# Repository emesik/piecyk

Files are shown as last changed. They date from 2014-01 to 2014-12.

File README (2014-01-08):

This is my first project based on AVR microcontroller (and any MCU in general).
It is used to keep track of temperature and control the heating system at home.

General principles:
 * piecyk measures temperature using LM35 analog sensor,
 * it has MIN and MAX temperature defined,
 * whenever current temperature drops to MIN or below, the heating is turned on,
 * whenever current temperature rises to MAX or over, the heating is turned off,
 * such a switch is being done using a NPN transistor to enable +12V DC circuit,
 * same circuit is used to power the controller itself, stepped down to +5V DC,
 * both MIN and MAX temperatures are programmable by MODE, UP and DOWN buttons,
 * a 2x16 LCD displays all these three values,
 * a LED turns on together with the heating.

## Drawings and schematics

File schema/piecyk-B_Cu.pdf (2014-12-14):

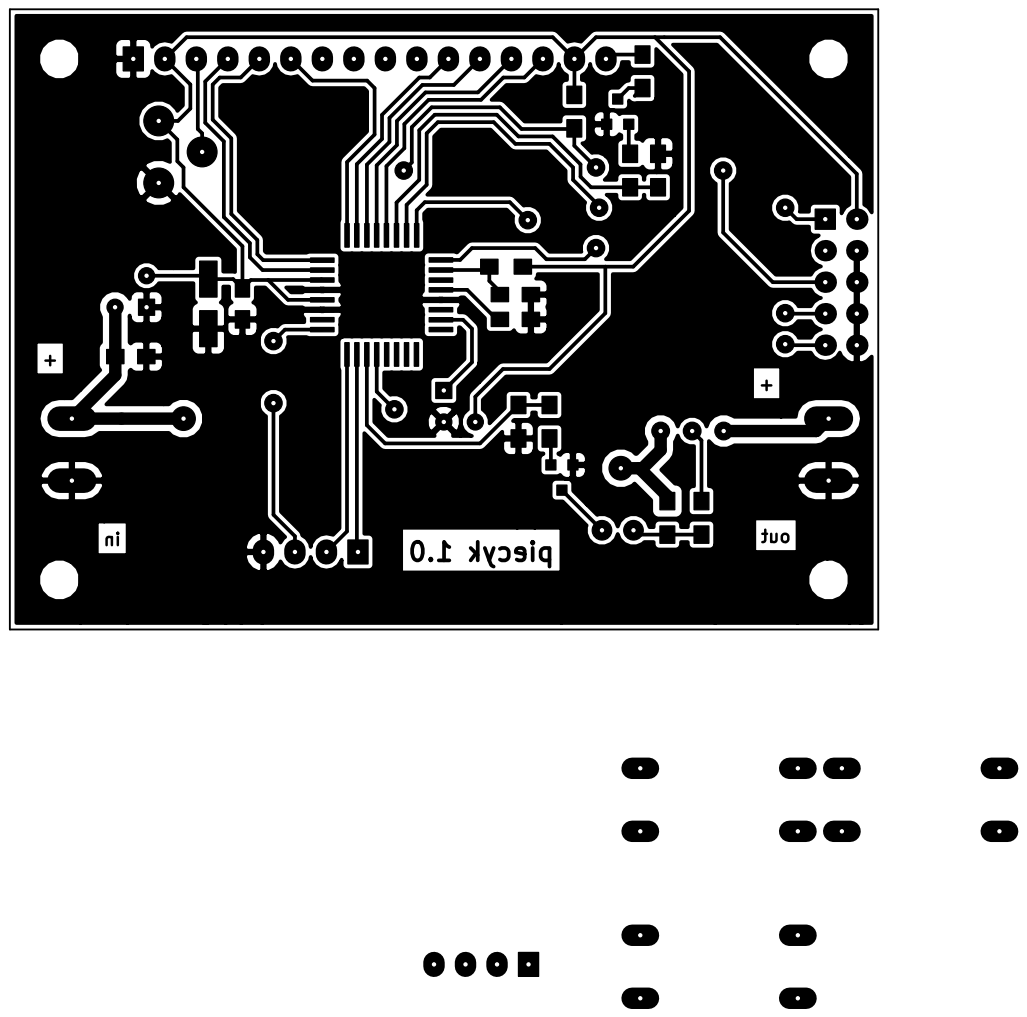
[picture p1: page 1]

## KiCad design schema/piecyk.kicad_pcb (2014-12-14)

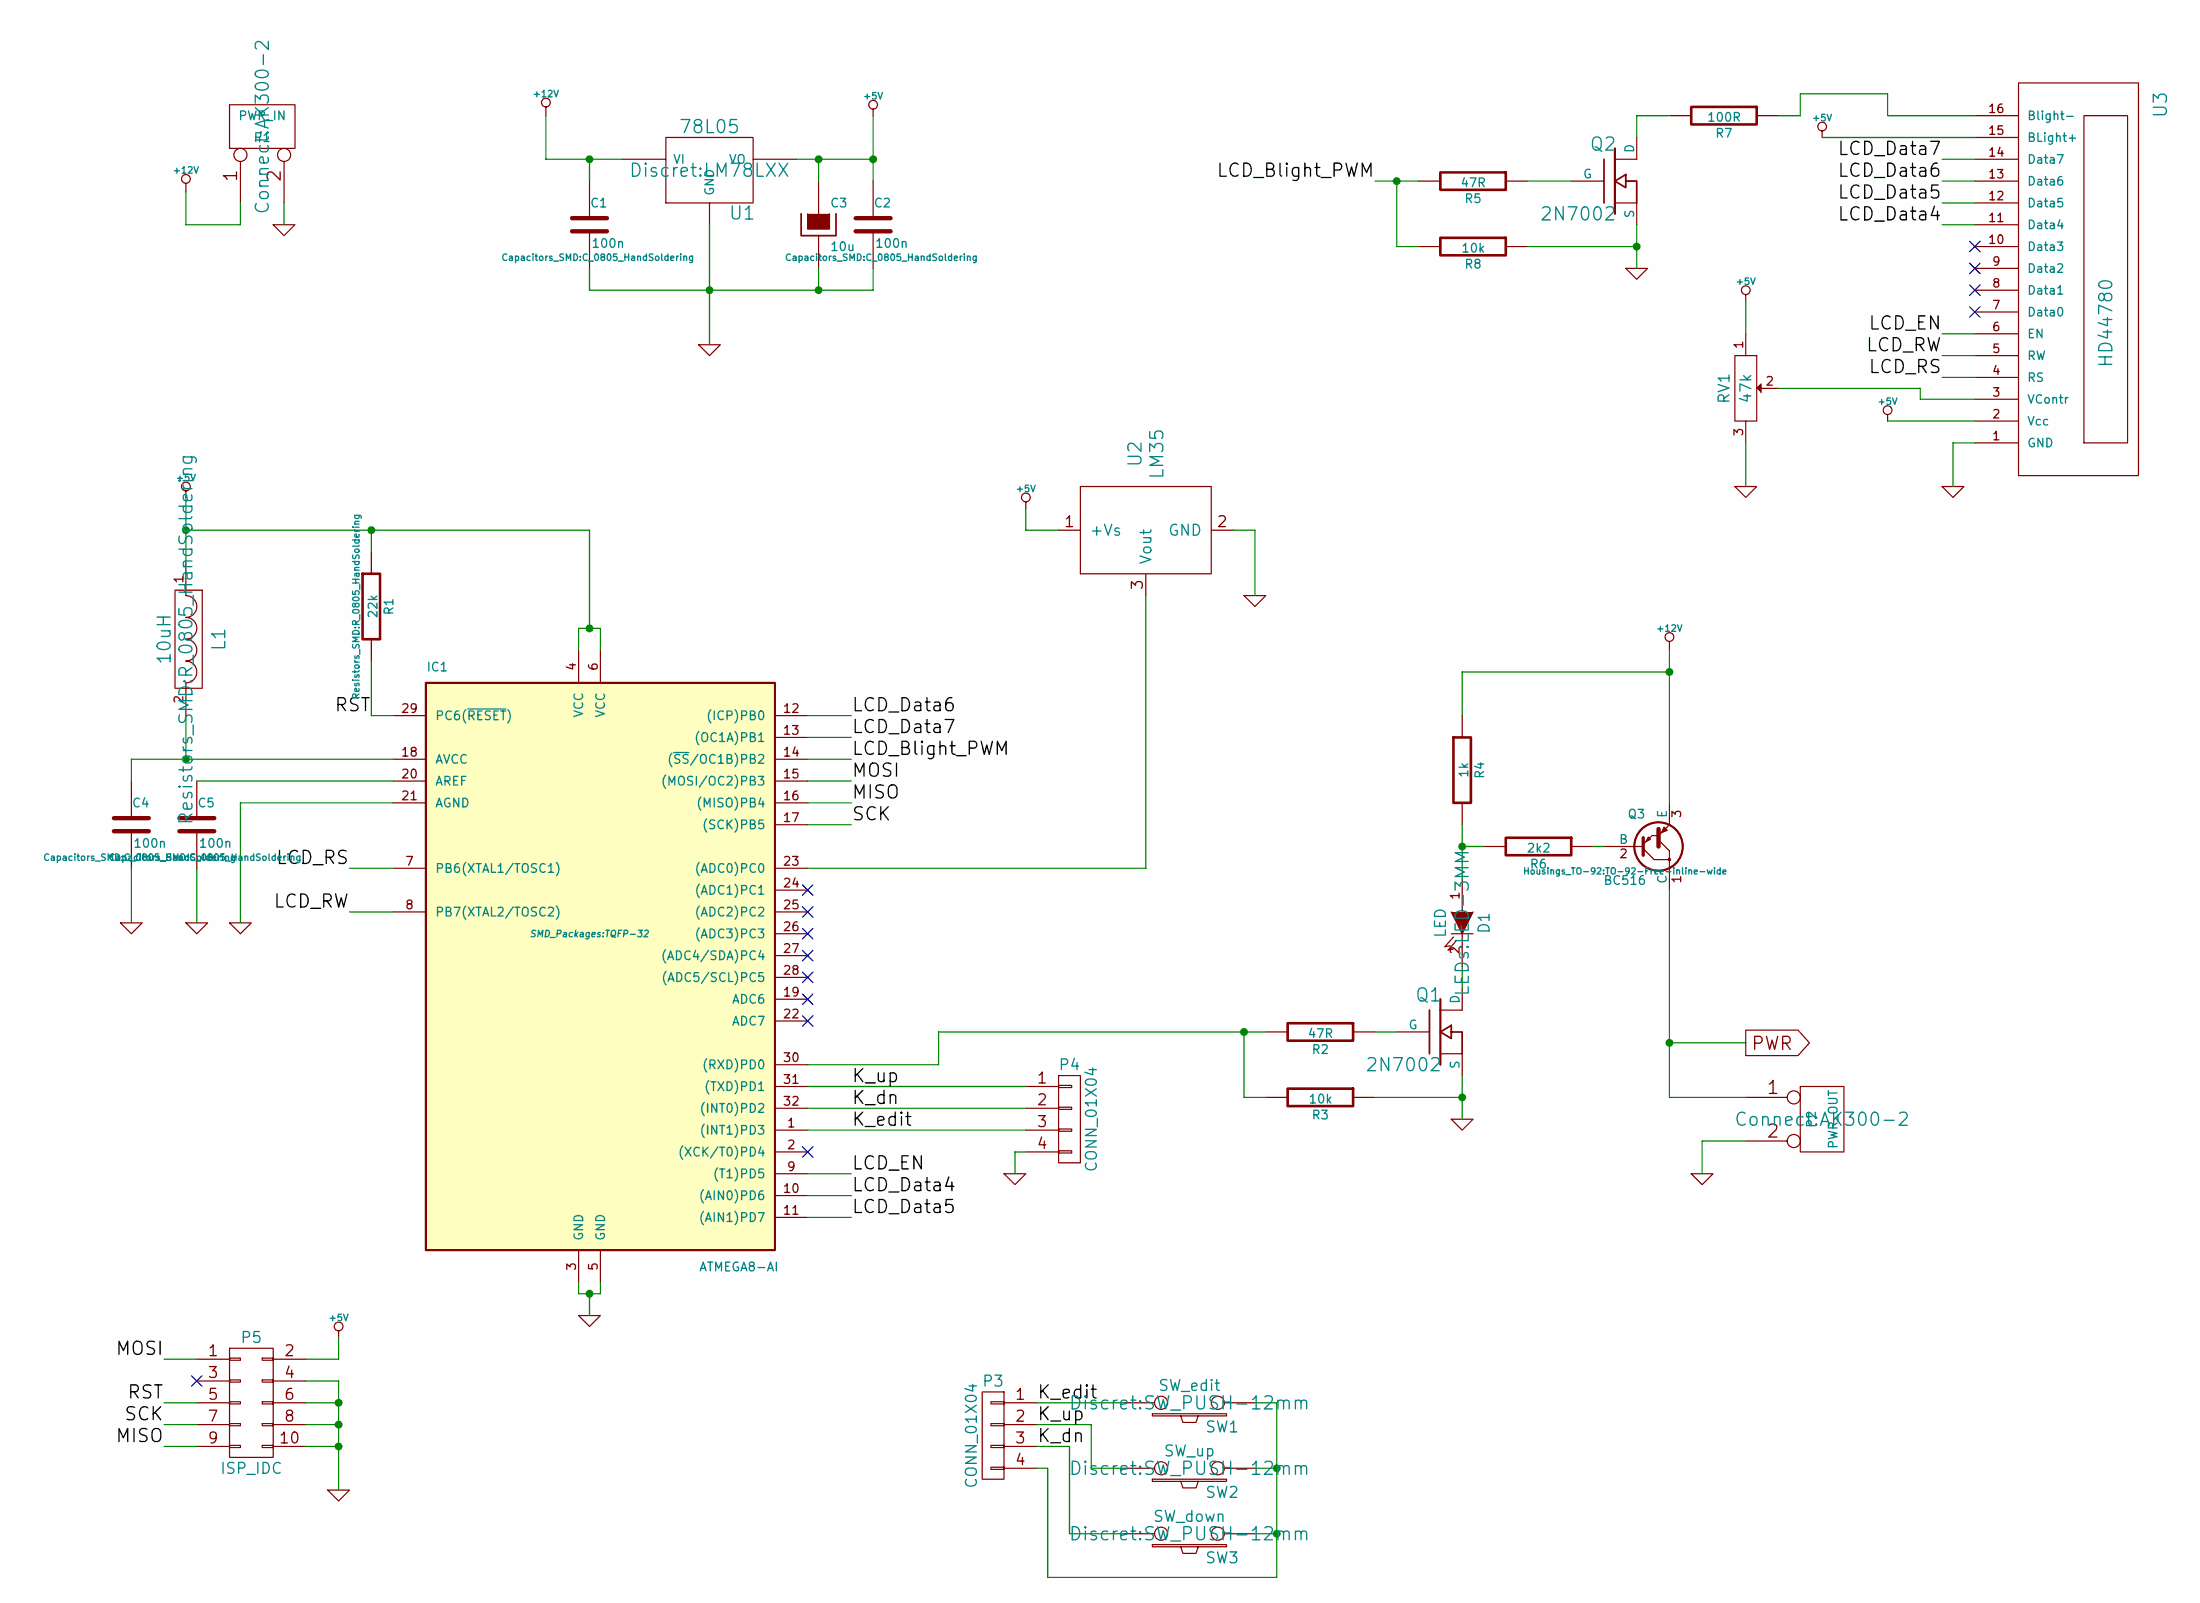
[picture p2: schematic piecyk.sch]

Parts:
C1, C2, C4, C5: 100n; C_0805_HandSoldering
C3: 10u; TantalC_SizeA_EIA-3216_HandSoldering
D1: LED; LED-3MM
IC1: ATMEGA8-AI; TQFP-32
L1: 10uH; R_0805_HandSoldering
P1: PWR_IN; AK300-2
P2: PWR_OUT; AK300-2
P3, P4: CONN_01X04; Pin_Header_Angled_1x04
P5: ISP_IDC; Pin_Header_Straight_2x05
Q1, Q2: 2N7002; SOT-23-GDS
Q3: BC516; TO-92-Free-inline-wide
R1: 22k; R_0805_HandSoldering
R2, R5: 47R; R_0805_HandSoldering
R3, R8: 10k; R_0805_HandSoldering
R4: 1k; R_0805_HandSoldering
R6: 2k2; R_0805_HandSoldering
R7: 100R; R_0805_HandSoldering
RV1: 47k; Potentiometer_VishaySpectrol-Econtrim-Type36P
SW1: SW_edit; SW_PUSH-12mm
SW2: SW_up; SW_PUSH-12mm
SW3: SW_down; SW_PUSH-12mm
U1: 78L05; LM78LXX
U2: LM35
U3: HD44780; Pin_Header_Straight_1x16

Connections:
+5V: C2.1, C3.1, IC1.4 (VCC), IC1.6 (VCC), L1.1, P5.2, R1.1, RV1.1, U1.VO, U2.1 (+Vs), U3.2 (Vcc), U3.15 (BLight+)
+12V: C1.1, P1.1, Q3.3 (E), R4.1, U1.VI
/K_dn: IC1.32 ((INT0)PD2), P3.3, P4.2, SW3.1
/K_edit: IC1.1 ((INT1)PD3), P3.1, P4.3, SW1.1
/K_up: IC1.31 ((TXD)PD1), P3.2, P4.1, SW2.1
/LCD_Blight_PWM: IC1.14 ((~SS~/OC1B)PB2), R5.2, R8.2
/LCD_Data4: IC1.10 ((AIN0)PD6), U3.11 (Data4)
/LCD_Data5: IC1.11 ((AIN1)PD7), U3.12 (Data5)
/LCD_Data6: IC1.12 ((ICP)PB0), U3.13 (Data6)
/LCD_Data7: IC1.13 ((OC1A)PB1), U3.14 (Data7)
/LCD_EN: IC1.9 ((T1)PD5), U3.6 (EN)
/LCD_RS: IC1.7 (PB6(XTAL1/TOSC1)), U3.4 (RS)
/LCD_RW: IC1.8 (PB7(XTAL2/TOSC2)), U3.5 (RW)
/MISO: IC1.16 ((MISO)PB4), P5.9
/MOSI: IC1.15 ((MOSI/OC2)PB3), P5.1
/RST: IC1.29 (PC6(~RESET~)), P5.5, R1.2
/SCK: IC1.17 ((SCK)PB5), P5.7
GND: C1.2, C2.2, C3.2, C4.2, C5.2, IC1.3 (GND), IC1.5 (GND), IC1.21 (AGND), P1.2 (PM), P2.2 (PM), P4.4, P5.4, P5.6, P5.8, P5.10, Q1.S, Q2.S, R3.1, R8.1, RV1.3, U1.GND, U2.2 (GND), U3.1 (GND)
unnamed: C4.1, IC1.18 (AVCC), L1.2
unnamed: C5.1, IC1.20 (AREF)
unnamed: D1.1 (A), R4.2, R6.2
unnamed: D1.2 (K), Q1.D
unnamed: IC1.23 ((ADC0)PC0), U2.3 (Vout)
unnamed: IC1.30 ((RXD)PD0), R2.2, R3.2
unnamed: P3.4, SW1.2, SW2.2, SW3.2
unnamed: Q1.G, R2.1
unnamed: Q2.D, R7.2
unnamed: Q2.G, R5.1
unnamed: Q3.2 (B), R6.1
unnamed: R7.1, U3.16 (Blight-)
unnamed: RV1.2, U3.3 (VContr)
PWR: P2.1, Q3.1 (C)

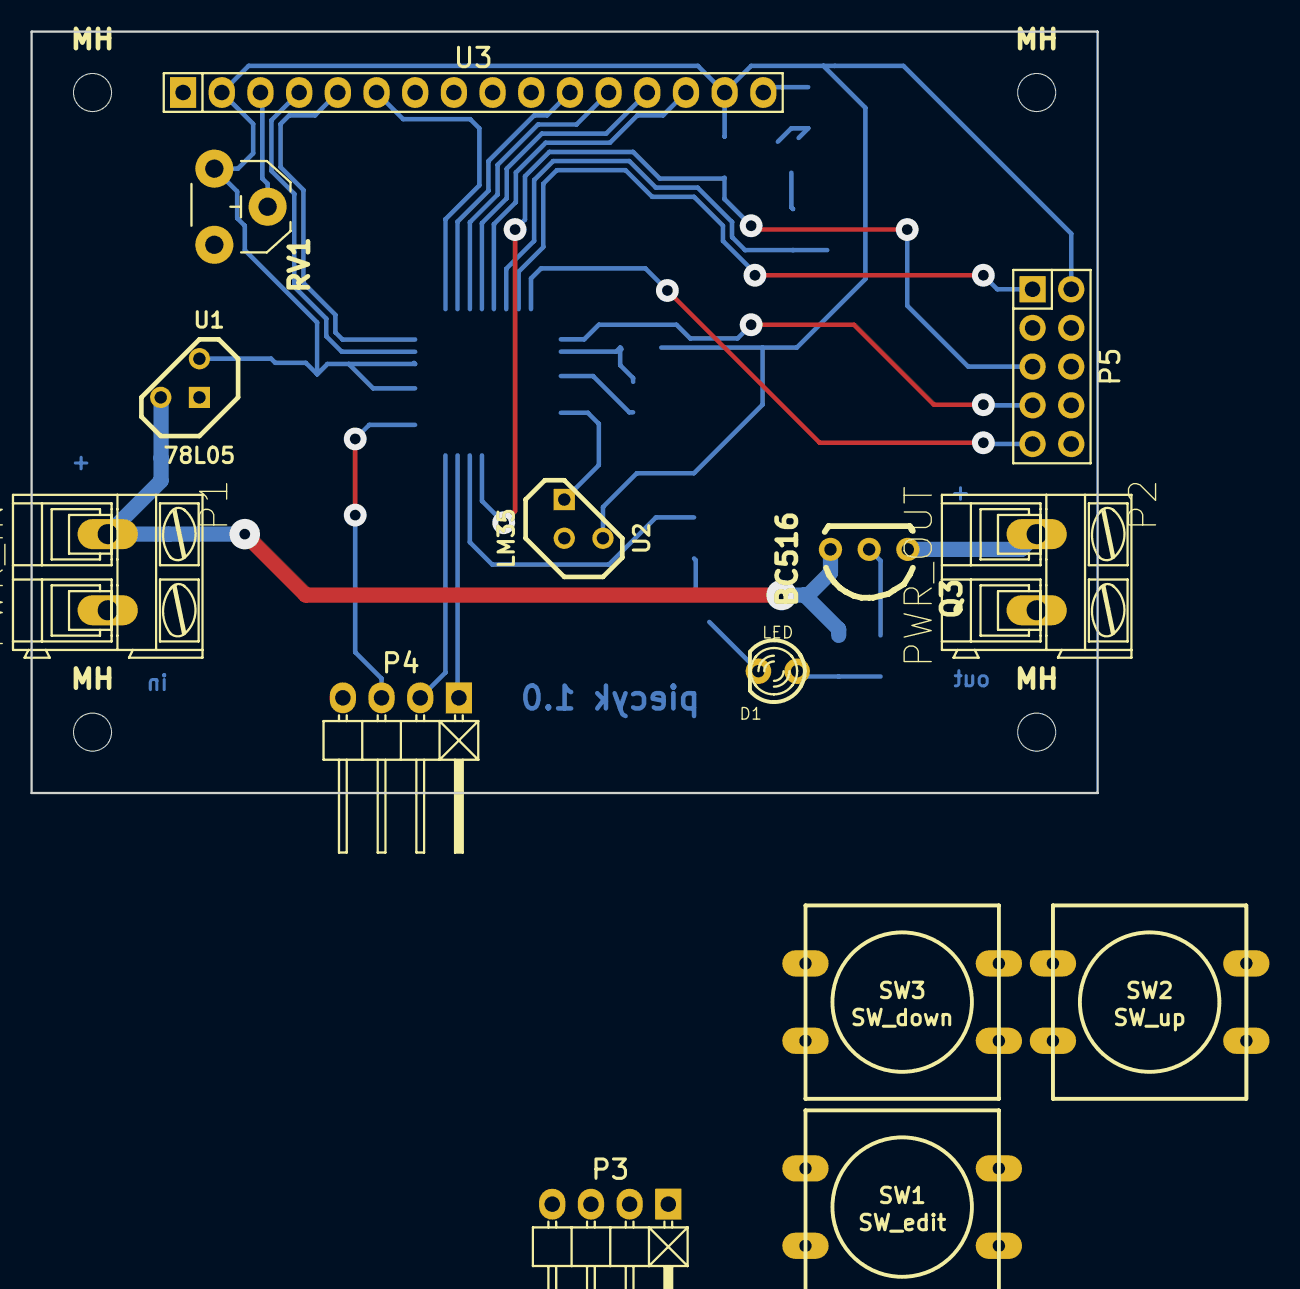
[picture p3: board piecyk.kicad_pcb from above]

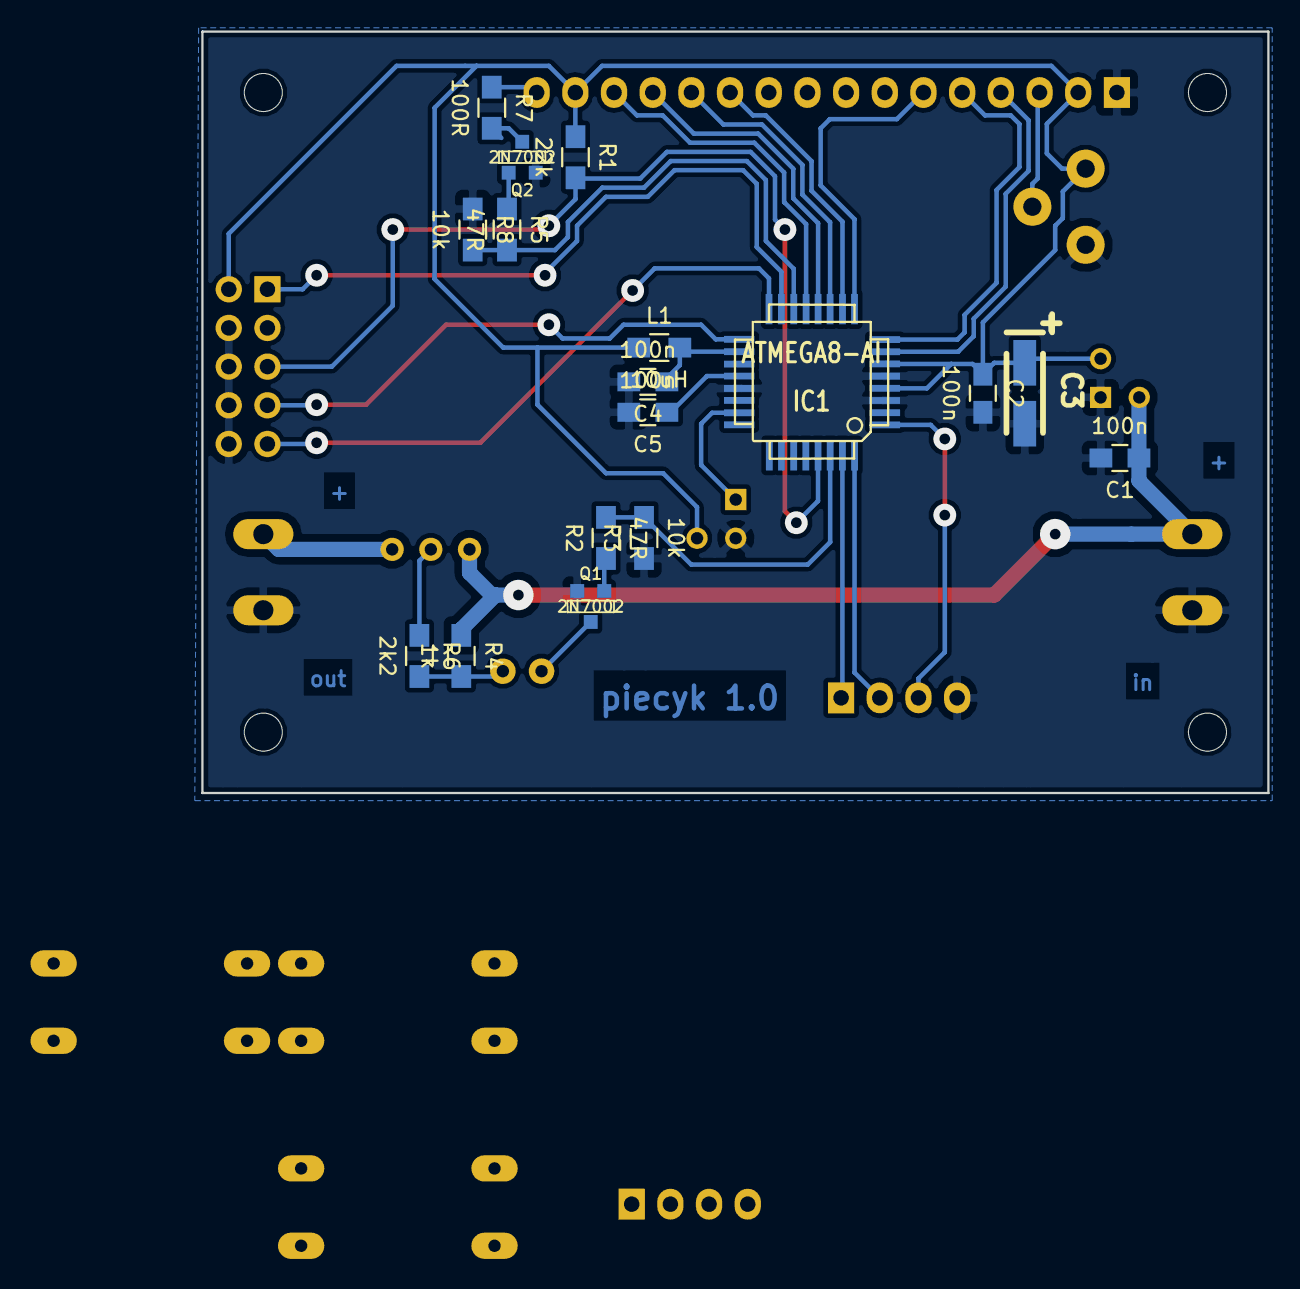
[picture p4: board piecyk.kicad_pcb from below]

Board: 2 copper layers, 70.0 x 50.0 mm, 35 parts (17 on the bottom side), 32 nets.

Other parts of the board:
MH: MountingHole_2-5mm_RevA_Date21Jun2010; MountingHole_2-5mm
MH#2, MH#3, MH#4: MountingHole_2-5mm_RevA_Date21Jun2010; MountingHole_2-5mm

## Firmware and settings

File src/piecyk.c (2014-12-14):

#include <stdlib.h>
#include <string.h>
#include <avr/interrupt.h>
#include <avr/io.h>
#include <avr/eeprom.h>
#include <avr/pgmspace.h>
#include <util/delay.h>

#include <hd44780_low.h>
#include <hd44780fw.h>

FUSES =
{
	.low = LFUSE_DEFAULT & FUSE_BODLEVEL & FUSE_BODEN,
	.high = HFUSE_DEFAULT & FUSE_EESAVE,
	/* WARNING: These settings cannot be written from a .hex file without external tools.
	 * Fusebits are redefined in Makefile and that setting is the working one.
	 */
};

/* The sensor shows some kind of variation, jumping even a full centigrade every
 * few seconds. For the heating we need very slow responsiveness, so the samples
 * will be gathered in a table and averaged.
 */
#ifdef DEBUG
#define		SAMPLE_BUFFER_SIZE	10
#else
#define		SAMPLE_BUFFER_SIZE	100		// remember this chip has 1K only
#endif
#define		INVALID_TEMP		-(300 << 2)	// mordor
int16_t *samples;		// keep full 10-bit sample
unsigned int samples_idx = 0;
uint8_t buffer_filled = 0;

/* WARNING: all temperatures are measured in 0,25C units, 10 bit */
#define		MIN_VALID_TEMP	0
#define		MAX_VALID_TEMP	(50 << 2)
#define		DEFAULT_MIN		(22 << 2)		// 22,00
#define		DEFAULT_MAX		(22 << 2) + 2	// 22,50
uint16_t volatile temp_min = DEFAULT_MIN, temp_max = DEFAULT_MAX;
uint8_t heating_state = 0;

// the permanent storage of programmed temps and last state
uint16_t EEMEM perm_temp_min = DEFAULT_MIN;
uint16_t EEMEM perm_temp_max = DEFAULT_MAX;
uint8_t EEMEM perm_heating_state = 1;
uint8_t need_store = 0;

inline void restore_parameters()
{
	cli();
	eeprom_busy_wait();
	temp_min = eeprom_read_word(&perm_temp_min);
	temp_max = eeprom_read_word(&perm_temp_max);
	heating_state = eeprom_read_byte(&perm_heating_state);
	sei();
}

void save_parameters()
{
	cli();
	eeprom_busy_wait();
	eeprom_write_word(&perm_temp_min, temp_min);
	eeprom_write_word(&perm_temp_max, temp_max);
	eeprom_write_byte(&perm_heating_state, heating_state);
	sei();
}

// The LCD configs
struct hd44780fw_conf lcd_conf;
struct hd44780_l_conf lcd_low_conf;
volatile uint8_t display_need_refresh = 0;

/*
 *	The LCD desired structure during normal operation
 *	   0123456789abcdef
 *
 *	0  Temp= *Max 21,0C
 *	1  20,5C *Min 20,0C
 *
 *	         ^-------- indicates the value is being edited
 *
 */
#define		DISPLAY_SIZE	0x20
#define		GATHER_IDX		0x04
#define		CUR_VAL_IDX		0x10
#define		MIN_EDIT_IDX	0x16
#define		MIN_VAL_IDX		0x1b
#define		MAX_EDIT_IDX	0x06
#define		MAX_VAL_IDX		0x0b

const char template[DISPLAY_SIZE] PROGMEM	= "Temp   Max     C    C  Min     C";
const char intro[DISPLAY_SIZE] PROGMEM		= "piecyk v1.0     zaraz grzejemy! ";
const char fractions[4] PROGMEM = "0358";

#define		MIN_BRIGHTNESS	0x0060
#define		MAX_BRIGHTNESS	0x0300
#define		DIM_STEP_UP		16
#define		DIM_STEP_DN		3
uint16_t	brightness = MIN_BRIGHTNESS;
#define		IDLE_TOP		0x60
uint16_t	idle = IDLE_TOP;

inline void init_display()
{
	char *display_buf = malloc(DISPLAY_SIZE + 1);

	// init backlight PWM
	DDRB |= (1 << PB2);
	// phase-correct 10bit PWM, OC1B output
	TCCR1A = (1 << COM1B1) | (1 << WGM10) | (1 << WGM11);
	// /8 prescaler
	TCCR1B = (1 << CS11);
	// enable overflow interrupt
	TIMSK = (1 << TOIE1);
	OCR1BH = (uint8_t)(brightness >> 8);
	OCR1BL = (uint8_t)(brightness & 0xff);

	// pins connected to PORTB
	DDRB |= (1 << PB7) | (1 << PB6) | (1 << PB1) | (1 << PB0);
	lcd_low_conf.rs_i = 6;
	lcd_low_conf.rw_i = 7;
	lcd_low_conf.db6_i = 0;
	lcd_low_conf.db7_i = 1;

	lcd_low_conf.rs_port =
	lcd_low_conf.rw_port =
	lcd_low_conf.db6_port =
	lcd_low_conf.db7_port =
	&PORTB;

	// pins connected to PORTD
	DDRD |= (1 << PD5) | (1 << PD6) | (1 << PD7);
	lcd_low_conf.en_i = 5;
	lcd_low_conf.db4_i = 6;
	lcd_low_conf.db5_i = 7;

	lcd_low_conf.en_port =
	lcd_low_conf.db4_port =
	lcd_low_conf.db5_port =
	&PORTD;

	lcd_low_conf.line1_base_addr = 0x00;
	lcd_low_conf.line2_base_addr = 0x40;
	lcd_low_conf.dl = HD44780_L_FS_DL_4BIT;
	lcd_conf.low_conf = &lcd_low_conf;
	lcd_conf.total_chars = 32;
	lcd_conf.font = HD44780_L_FS_F_58;
	lcd_conf.lines = HD44780_L_FS_N_DUAL;

	hd44780fw_init(&lcd_conf);
	hd44780_l_disp(&lcd_low_conf, HD44780_L_DISP_D_ON, HD44780_L_DISP_C_OFF, HD44780_L_DISP_B_OFF);

	memcpy_P(display_buf, &intro, DISPLAY_SIZE);
	*(display_buf + DISPLAY_SIZE) = '\0';
	hd44780fw_write(&lcd_conf, display_buf, 0, HD44780FW_WR_CLEAR_BEFORE);

	display_need_refresh = 1;
	free(display_buf);
}

inline void init_analog_temp()
{
	/*
	 * Based on https://sites.google.com/site/qeewiki/books/avr-guide/analog-input
	 *
	 * Initialize ADMUX register with new value
	 * REFS0 = 1, REFS1 = 1:	use Aref
	 * ADLAR = 0:				10-bit resolution
	 * MUX = 0:					ADC0 (PC0) is the input
	 */
	ADMUX = (1 << REFS0) | (1 << REFS1);
	// enable ADC, set 128 prescaler
	ADCSRA |= (1 << ADEN) | (1 << ADPS2) | (1 << ADPS1) | (1 << ADPS0);
	// set other pins as output and set high state
	DDRC = ~(1 << PC0);
	PORTC |= ~(1 << PC0);
	// create buffer for samples and empty it
	samples = malloc(SAMPLE_BUFFER_SIZE * sizeof(int16_t));
	for (unsigned int i = 0; i < SAMPLE_BUFFER_SIZE; i++) *(samples + i) = INVALID_TEMP;
}

inline void read_temp()
{
	int adcval;
	// start conversion
	ADCSRA |= (1 << ADSC);
	// spinlock until finished
	while (ADCSRA & (1 << ADSC));

	/*
	 * The docs say reading the higher byte causes update. This should not be the case in
	 * per-request conversion, but we keep the convention of reading lower byte first.
	 *
	 */
	adcval = ADCL;
	adcval = (ADCH << 8) + adcval;

	/*
	 * LM35 returns linear function of temperature in Celsius:
	 * Vout = 0V + (t * 0.01V)
	 * As we have 2.56V as Aref and 1024 values of 10-bit resolution,
	 * the maximum resolution is 0,25C.
	 *
	 * We keep full sample.
	 *
	 */
	*(samples + samples_idx++) = adcval;
	// cycle buffer
	if (samples_idx >= SAMPLE_BUFFER_SIZE) samples_idx = 0;
}

uint16_t get_avg_temp()
{
	unsigned int counted = SAMPLE_BUFFER_SIZE;
	uint32_t sum = 0;

	buffer_filled = 1;
	for (unsigned int i = 0; i < SAMPLE_BUFFER_SIZE; i++) {
		if (*(samples + i) == INVALID_TEMP) {
			counted--;
			buffer_filled = 0;
			continue;
		}
		sum += *(samples + i);
	}
	return sum / counted;
}

#define		KEY_DOWN	(1 << PD2)
#define		KEY_UP		(1 << PD1)
#define		KEY_EDIT	(1 << PD3)
#define		KEYS_ALL	(KEY_EDIT | KEY_DOWN | KEY_UP)

#define		EDIT_NONE		0
#define		EDIT_MAX		1
#define		EDIT_MIN		2
#define		EDIT_INVALID	3
volatile uint8_t edit_mode = EDIT_NONE;

ISR(TIMER0_OVF_vect)
{
	static uint8_t kbd_state, kbd_state_old = 0;
	static uint8_t need_reaction = 0, reacted_state = 0;

	// Switches lower the pin state, so we use negative value
	kbd_state = ~PIND & KEYS_ALL;

	/*
	 * Debouncing, as in:
	 * http://mikrokontrolery.blogspot.com/2011/03/epp-eliminacja-drgan-stykow-omicronns.html
	 *
	 */
	if ((kbd_state == kbd_state_old) && (kbd_state != reacted_state)) {
		need_reaction = 1;
		reacted_state = kbd_state;
	}

	kbd_state_old = kbd_state;

	// React to the keypad state
	if (!need_reaction) return;
	if (kbd_state & KEY_EDIT) {
		// this is not atomic, so we use a temporary var
		uint8_t _edit_mode = edit_mode;
		_edit_mode++;
		if (_edit_mode == EDIT_INVALID) _edit_mode = EDIT_NONE;
		edit_mode = _edit_mode;
	} else if (kbd_state & KEY_DOWN) {
		if ((edit_mode == EDIT_MIN) && (temp_min > MIN_VALID_TEMP)) temp_min--;
		if ((edit_mode == EDIT_MAX) && (temp_max > MIN_VALID_TEMP) &&
				(temp_max > temp_min)) temp_max--;
	} else if (kbd_state & KEY_UP) {
		if ((edit_mode == EDIT_MIN) && (temp_min < MAX_VALID_TEMP) &&
				(temp_min < temp_max)) temp_min++;
		if ((edit_mode == EDIT_MAX) && (temp_max < MAX_VALID_TEMP)) temp_max++;
	}

	need_store = 1;
	need_reaction = 0;
	display_need_refresh = 1;

	idle = IDLE_TOP;
	brightness = MAX_BRIGHTNESS;
}

ISR(TIMER1_OVF_vect) {
	uint16_t cur_bright;

	// increase/decrease duty cycle to target level
	cur_bright = OCR1BL;
	cur_bright |= (OCR1BH << 8);
	if (cur_bright < brightness - DIM_STEP_UP) cur_bright += DIM_STEP_UP;
	if (cur_bright > brightness + DIM_STEP_DN) cur_bright -= DIM_STEP_DN;
	OCR1BH = (uint8_t)(cur_bright >> 8);
	OCR1BL = (uint8_t)(cur_bright & 0xff);
}

void temptoa(uint16_t temp, char *rbuf)
{
	/* Converts 10-bit temp to string with one fraction digit.
	 * The number gets rounded: ,25 = ,3 and ,75 = ,8
	 *
	 * Does not terminate the string with \0,
	 * allowing simple pasting into the template. */
	char *buf = malloc(4);
	size_t s = 0;

	// integer part: all but lowest 2 bits
	itoa((temp >> 2), buf, 10);
	s = strlen(buf);
	memcpy(rbuf + (2-s), buf, s);

	*(rbuf + 2) = ',';
	// fraction part: lowest 2 bits
	*(rbuf + 3) = pgm_read_byte(&fractions[temp & 3]);
	free(buf);
}

void refresh_display()
{
	// allocate once and for all
	static char *display_buf = NULL;
	if (display_buf == NULL) display_buf = malloc(DISPLAY_SIZE + 1);

	memcpy_P(display_buf, &template, DISPLAY_SIZE);
	// Update values
	if (buffer_filled)
		*(display_buf + GATHER_IDX) =  ' ';
	else
		*(display_buf + GATHER_IDX) =  '=';
	temptoa(get_avg_temp(), display_buf + CUR_VAL_IDX);
	temptoa(temp_min, display_buf + MIN_VAL_IDX);
	temptoa(temp_max, display_buf + MAX_VAL_IDX);
	if (edit_mode == EDIT_MIN)
		*(display_buf + MIN_EDIT_IDX) = '*';
	else
		*(display_buf + MIN_EDIT_IDX) = ' ';
	if (edit_mode == EDIT_MAX)
		*(display_buf + MAX_EDIT_IDX) = '*';
	else
		*(display_buf + MAX_EDIT_IDX) = ' ';
	*(display_buf + DISPLAY_SIZE) = '\0';
	// Write the string to the display
	hd44780fw_write(&lcd_conf, display_buf, 0, HD44780FW_WR_NO_CLEAR_BEFORE);
	display_need_refresh = 0;
}

inline void init_keypad()
{
	DDRD &= ~KEYS_ALL;
	PORTD |= KEYS_ALL;	// pull-up

	// use internal clock, 256 prescaler
	TCCR0 |= (1 << CS02);

	// enable timer overflow interrupt
	TIMSK |= (1 << TOIE0);
}

inline void turn_heating(uint8_t on)
{
	if (on) {
		PORTD &= ~(1 << PD0);
	} else {
		PORTD |= (1 << PD0);
	}

	idle = IDLE_TOP;
	brightness = MAX_BRIGHTNESS;
}

inline void init_heating()
{
	DDRD |= (1 << PD0);
	turn_heating(heating_state);
}

inline void control_heating()
{
	uint16_t temp = get_avg_temp();
	if (!buffer_filled) return;	// no balanced data yet
	if ((temp < temp_min) && heating_state == 0) {
		heating_state = 1;
		turn_heating(heating_state);
		need_store = 1;
	} else if ((temp > temp_max) && heating_state == 1) {
		heating_state = 0;
		turn_heating(heating_state);
		need_store = 1;
	}
}

int main()
{
	init_display();
	restore_parameters();
	init_heating();
	init_analog_temp();
	init_keypad();
	sei();
	_delay_ms(1000);	// let the intro be visible but already gather data
	for (unsigned int lcx = 0;; lcx++) {
		_delay_ms(31);		// ~32Hz
		if (!(lcx & 0x1f)) {
			// read temp and update heating state every 32 cycles
			read_temp();
			control_heating();
		}

		// refresh when needed or every 32 cycles
		if (display_need_refresh || (lcx & 0x1f)) {
			refresh_display();
		}

		if (need_store) save_parameters();

		if (idle == 0) brightness = MIN_BRIGHTNESS;
		else idle--;
	}
	return 0;
}

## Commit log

2014-01-06 Remove fat *printf, save 2k of binary code size
2014-01-08 Add temperature reading, averaging and displaying
2014-01-08 Reduce refresh and screen flickering, gather samples when welcome text is on
2014-01-09 Introduce pinout for the final board
2014-01-11 Add KiCAD schema
    [piecyk.sch]
2014-01-11 Correct schematics (NPN instead of PNP)
    [piecyk.sch]
2014-01-12 Correct capacitors
    [piecyk.sch]
2014-01-12 Make global used in interrupt volatile
2014-01-12 Set fuse bits
2014-01-31 Use full 10-bit numbers for temperature settings
2014-02-01 Reprogram fuses, set clock to 8MHz
2014-11-08 Add PCB layout, rearrange pins a bit to clean up tracks
    [piecyk.kicad_pcb, piecyk.sch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]
2014-12-11 Use more compact SMD components
    [piecyk.kicad_pcb, piecyk.sch]
2014-12-11 Add PWM dimming of the display
2014-12-12 Add 10uF capacitor, optimalize PCB layout
    [piecyk.kicad_pcb, piecyk.sch]
2014-12-12 Change resistor from 1k to 2k2 to limit base current
    [piecyk.sch]
2014-12-12 Add I/O markings to the PCB
    [piecyk.kicad_pcb]
2014-12-12 Rem obsolete file
    [piecyk.drl]
2014-12-13 Remove local libraries as the components are merged upstream
    [piecyk.kicad_pcb, piecyk.sch]
2014-12-13 Use actual keypad layout
    [piecyk.sch]
2014-12-13 Use new outputs. Diode is a part of the driving circuit.
2014-12-13 Correct output pin number
    [piecyk.c]
2014-12-14 Add missing pull-down resistor, adjust brightness levels
    [piecyk.kicad_pcb, piecyk.sch]
2014-12-14 Fix reversed switch behavior, reset idle counter only when switching
    [piecyk.c]
